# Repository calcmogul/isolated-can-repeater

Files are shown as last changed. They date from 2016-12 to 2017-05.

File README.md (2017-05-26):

# Galvanically Isolated CAN Repeater

This PCB is designed to function as a CAN repeater that galvanically isolates the two sides of the bus. It uses the repeater logic in figure 3 of AND8358/D (the application note for the AMIS-42700's feedback suppression).

## Hardware

* [Microcontroller](http://www.digikey.com/product-detail/en/texas-instruments/MSP430G2553IN20/296-28429-5-ND/2638885) (MSP430G2553) x1
* [Socket](http://www.digikey.com/product-detail/en/assmann-wsw-components/AR-20-HZL-TT/AE10015-ND/821769) (2x10 0.3" row spacing) x1
* [NOT Gates](http://www.digikey.com/product-detail/en/texas-instruments/CD4069UBE/296-3518-5-ND/376616) (CD4069UBE) x1
* [NAND Gates](http://www.digikey.com/product-detail/en/texas-instruments/CD4011BE/296-2031-5-ND/67241) (CD4011UBE) x1
* [CAN Transceiver](http://www.digikey.com/product-detail/en/texas-instruments/ISO1050DUBR/296-24818-2-ND/2094633) (ISO1050SUBR) x2
* [Voltage Regulator 3.3V](https://www.digikey.com/product-detail/en/stmicroelectronics/LD1117V33/497-1491-5-ND/586012) (LD1117V33) x1
* [0.1μF Capacitor](http://www.digikey.com/product-detail/en/vishay-bc-components/K104Z15Y5VF5TL2/BC1160CT-ND/286782) x1
* [10μF Capacitor](http://www.digikey.com/product-detail/en/tdk-corporation/FK24X5R1C106K/445-8497-ND/2815427) x1

### Thruhole

* 1x4 pin header x3

### SMT

* 2x6 pin header x1

## MSP430 Software

See [MSP430 README](msp430/README.md).

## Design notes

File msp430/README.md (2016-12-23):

# MSP430 Software

## Dependencies

* msp430-elf-gcc
* mspdebug

## Max operation speed of circuit

The falling edge of the output needs to track the input within one clock cycle of the CAN bus. Otherwise, one side of the bus will temporarily give up dominant status on the bus to the other side unintentionally.

measured delay between a falling edge on the input and the output tracking it:
> 1.88us (compiled with -O3 and using 16MHz main clock)

> 1/(1.88*1E-6)*1E-3 = ~531.9149kHz max switching frequency

So we could use a max bus speed of 500kHz with this hardware implementation.

The delay between the output tracking a rising edge on the input stops the local side of the bus from asserting dominance for a period of time so the other side of the bus may do so. This delay should be at least long enough for a falling edge (dominant state) to propagate across the bus.

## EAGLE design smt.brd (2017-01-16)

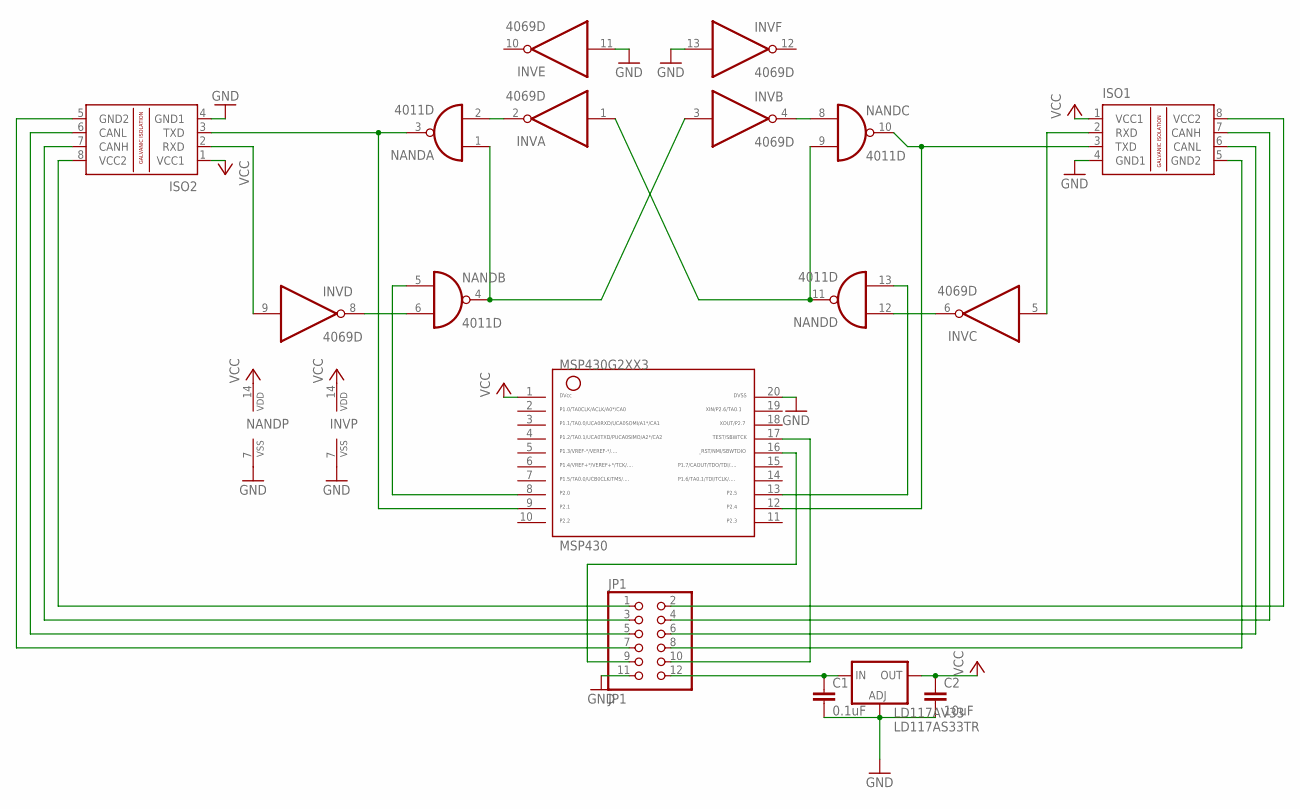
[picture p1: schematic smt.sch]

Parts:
C1: 0.1uF; C0402
C2: 10uF; C0402
INV: 4069D; SO14
ISO1, ISO2: ISO1050DUB; DUB-R-PDSO-G8
JP1: JP1; 2X06
LD117AV33: LD117AS33TR; SOT223
MSP430: G2XX3---PW20; PW20
NAND: 4011D; SO14

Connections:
GND: C1.2, C2.2, INV.7 (VSS), INV.11 (I), INV.13 (I), ISO1.4 (GND1), ISO2.4 (GND1), JP1.11, LD117AV33.1 (ADJ), MSP430.20, NAND.7 (VSS)
unnamed: JP1.9, MSP430.16
unnamed: JP1.10, MSP430.17
unnamed: INV.8 (O), NAND.6 (I1)
unnamed: INV.2 (O), NAND.2 (I1)
unnamed: INV.4 (O), NAND.8 (I0)
unnamed: INV.6 (O), NAND.12 (I0)
unnamed: INV.1 (I), NAND.9 (I1), NAND.11 (O)
unnamed: INV.3 (I), NAND.1 (I0), NAND.4 (O)
unnamed: ISO2.8 (VCC2), JP1.1
unnamed: ISO2.7 (CANH), JP1.3
unnamed: ISO2.6 (CANL), JP1.5
unnamed: ISO2.5 (GND2), JP1.7
unnamed: ISO1.8 (VCC2), JP1.2
unnamed: ISO1.7 (CANH), JP1.4
unnamed: ISO1.6 (CANL), JP1.6
unnamed: ISO1.5 (GND2), JP1.8
unnamed: INV.5 (I), ISO1.2 (RXD)
unnamed: INV.9 (I), ISO2.2 (RXD)
unnamed: MSP430.8, NAND.5 (I0)
unnamed: MSP430.13, NAND.13 (I1)
unnamed: C1.1, JP1.12, LD117AV33.3 (IN)
unnamed: ISO2.3 (TXD), MSP430.9, NAND.3 (O)
unnamed: ISO1.3 (TXD), MSP430.12, NAND.10 (O)
VCC: C2.1, INV.14 (VDD), ISO1.1 (VCC1), ISO2.1 (VCC1), LD117AV33.4 (OUT), MSP430.1, NAND.14 (VDD)

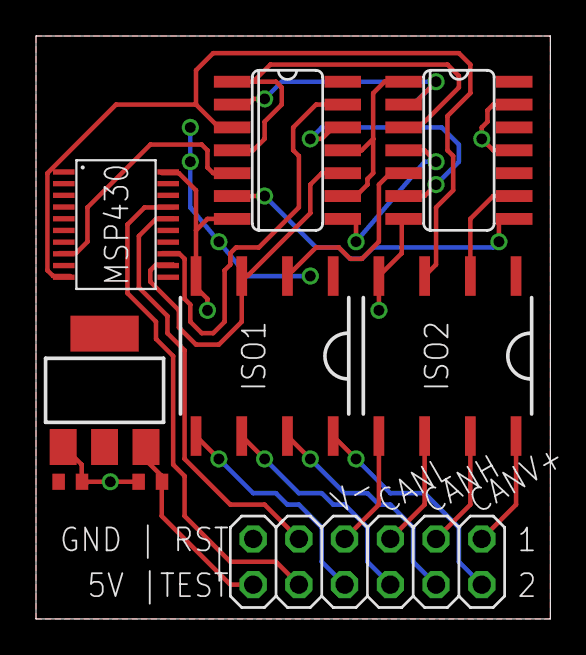
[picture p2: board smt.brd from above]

Board: 2 copper layers, 28.6 x 32.4 mm, 9 parts (0 on the bottom side), 25 nets.

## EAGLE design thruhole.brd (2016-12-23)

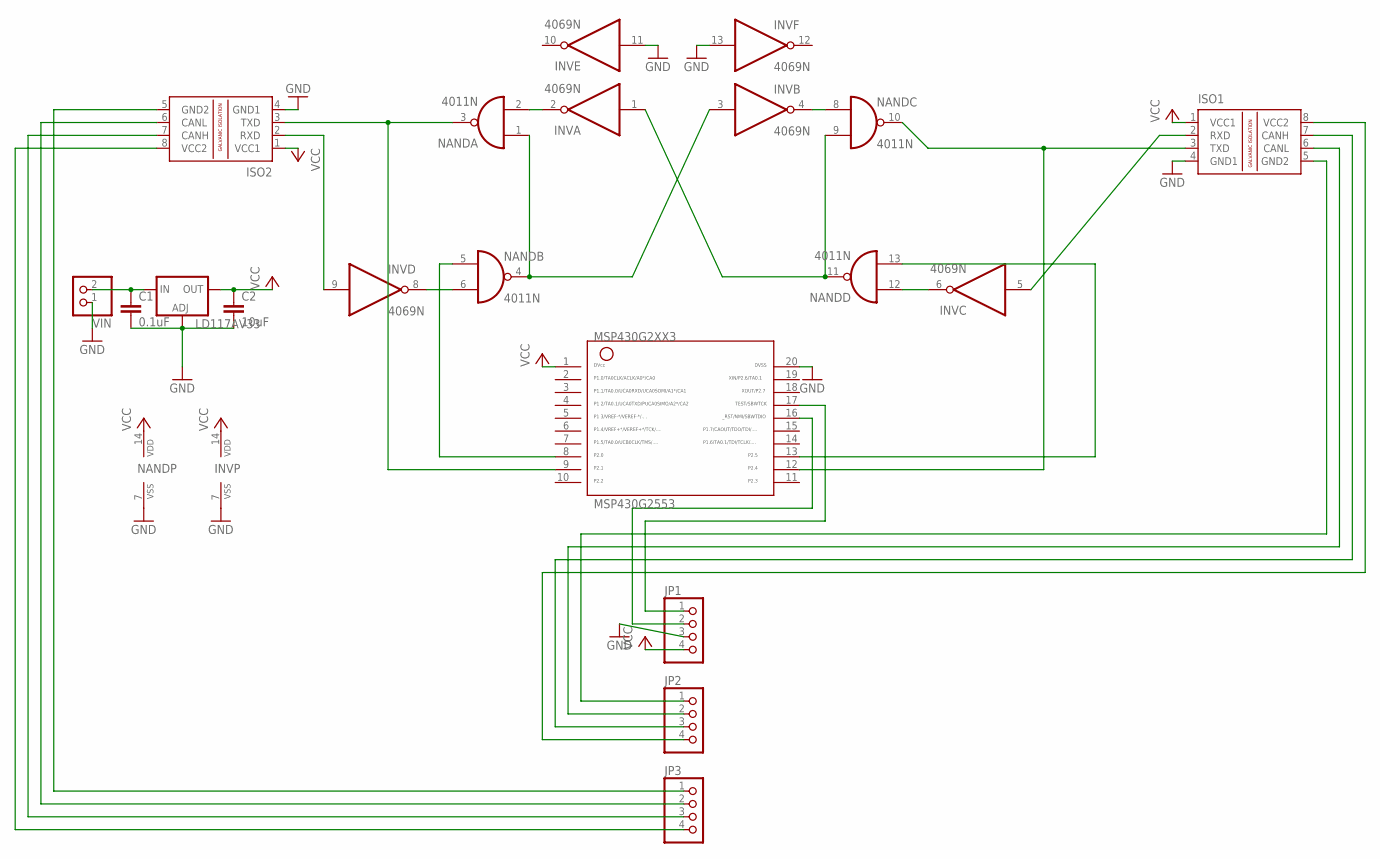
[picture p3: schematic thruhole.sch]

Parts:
C1: 0.1uF; C025-024X044
C2: 10uF; C025-024X044
INV: 4069N; DIL14
ISO1, ISO2: ISO1050DUB; DUB-R-PDSO-G8
JP1, JP2, JP3: PINHD-1X4; 1X04
LD117AV33: LD117AV33; TO220L1
MSP430G2553: G2XX3---N20; N20
NAND: 4011N; DIL14
VIN: PINHD-1X2; 1X02

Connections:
GND: C1.2, C2.2, INV.7 (VSS), INV.11 (I), INV.13 (I), ISO1.4 (GND1), ISO2.4 (GND1), JP1.3, LD117AV33.1 (ADJ), MSP430G2553.20, NAND.7 (VSS), VIN.1
unnamed: JP1.2, MSP430G2553.16
unnamed: JP1.1, MSP430G2553.17
unnamed: INV.8 (O), NAND.6 (I1)
unnamed: INV.2 (O), NAND.2 (I1)
unnamed: INV.4 (O), NAND.8 (I0)
unnamed: INV.6 (O), NAND.12 (I0)
unnamed: INV.1 (I), NAND.9 (I1), NAND.11 (O)
unnamed: INV.3 (I), NAND.1 (I0), NAND.4 (O)
unnamed: ISO2.8 (VCC2), JP3.4
unnamed: ISO2.7 (CANH), JP3.3
unnamed: ISO2.6 (CANL), JP3.2
unnamed: ISO2.5 (GND2), JP3.1
unnamed: ISO1.8 (VCC2), JP2.4
unnamed: ISO1.7 (CANH), JP2.3
unnamed: ISO1.6 (CANL), JP2.2
unnamed: ISO1.5 (GND2), JP2.1
unnamed: INV.5 (I), ISO1.2 (RXD)
unnamed: INV.9 (I), ISO2.2 (RXD)
unnamed: MSP430G2553.8, NAND.5 (I0)
unnamed: MSP430G2553.13, NAND.13 (I1)
unnamed: C1.1, LD117AV33.3 (IN), VIN.2
unnamed: ISO2.3 (TXD), MSP430G2553.9, NAND.3 (O)
unnamed: ISO1.3 (TXD), MSP430G2553.12, NAND.10 (O)
VCC: C2.1, INV.14 (VDD), ISO1.1 (VCC1), ISO2.1 (VCC1), JP1.4, LD117AV33.2 (OUT), MSP430G2553.1, NAND.14 (VDD)

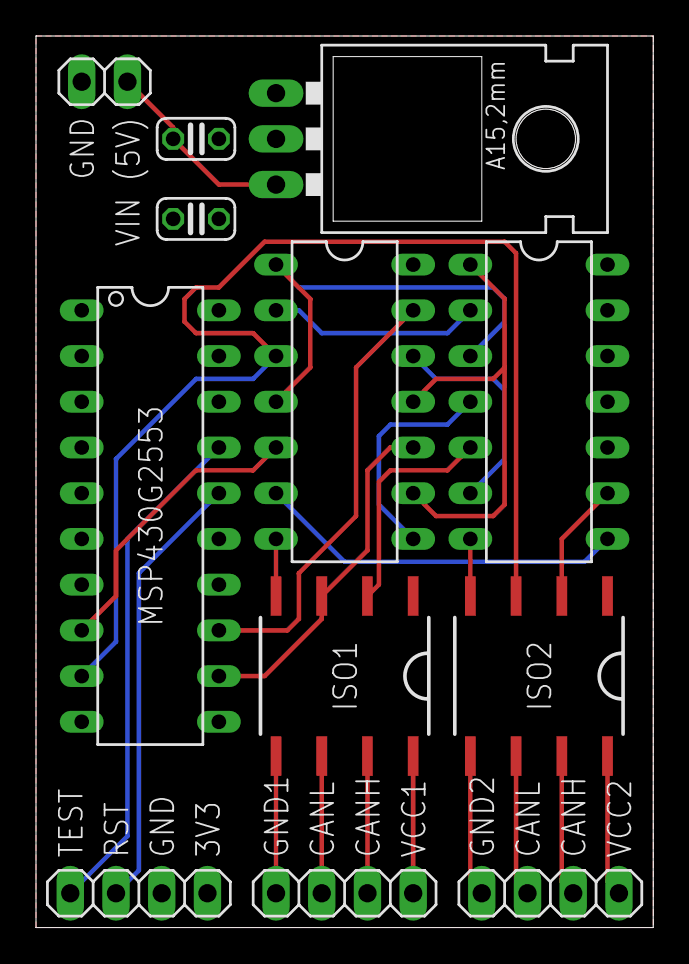
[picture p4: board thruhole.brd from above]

Board: 2 copper layers, 34.3 x 49.5 mm, 12 parts (0 on the bottom side), 25 nets.

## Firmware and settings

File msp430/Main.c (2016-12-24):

// Copyright (c) Tyler Veness 2016. All Rights Reserved.

#include <msp430g2553.h>
#include <stdint.h>

const uint16_t kDelayCount = 1600;

// 0 = low; 1 = high
uint8_t prevInputPins = 0;
uint8_t currentInputPins = 0;

void checkPins(const uint8_t input, const uint8_t output,
               volatile unsigned int* ACCR0, volatile unsigned int* CCTL1);

/*
 * Software loop is used instead of GPIO interrupts on edges because a rising
 * and falling edge can both occur while processing another interrupt. To avoid
 * that ambiguity, the edges are determined in the software loop at the rate
 * they can be processed.
 */
int main() {
  // Stop watchdog
  WDTCTL = WDTPW | WDTHOLD;

  // Set clock to 1 MHz
  DCOCTL = 0;
  BCSCTL1 = CALBC1_16MHZ;
  DCOCTL = CALDCO_16MHZ;

  // Configure P2.0, P2.1, P2.4, and P2.5 for GPIO
  P2SEL &= ~(BIT0 | BIT1 | BIT4 | BIT5);

  P2DIR |= BIT0;   // P2.0 = output for ISO2
  P2DIR &= ~BIT1;  // P2.1 = input for ISO2
  P2DIR &= ~BIT4;  // P2.4 = input for ISO1
  P2DIR |= BIT5;   // P2.5 = output for ISO1

  // Set ISO1 output high
  P2OUT |= BIT5;

  // Set ISO2 output high
  P2OUT |= BIT0;

  /* The delay from ISO1 CAN to ISO2 CAN is ~150ns (under typical conditions) -
   * it's the time needed to receive the signal on one bus plus the time needed
   * to transmit the signal on the other bus - the total delay is equal to the
   * loop delay of one transceiver.
   *
   * A delay of 300ns needs at least a 3.333MHz clock to capture one count.
   * kDelayCount = period * freq
   *             = std::ceil(300ns * 16MHz) to achieve minimum delay of 300ns
   */

  // Stop timer
  TA0CCR0 = 0;
  TA1CCR0 = 0;

  // CCIE = Interrupt when timer counts to TACCR0
  TA0CCTL0 = CCIE;
  TA1CCTL0 = CCIE;

  // Source Timer A from SMCLK (TASSEL_2), up mode (MC_1).
  // Up mode counts up to TACCR0. SLAU144J p. 358
  TA0CTL = TASSEL_2 | MC_1;
  TA1CTL = TASSEL_2 | MC_1;

  __bis_SR_register(GIE);

  while (1) {
    currentInputPins = P2IN;
    checkPins(BIT4, BIT5, &TA0CCR0, &TA0CCTL1);
    checkPins(BIT1, BIT0, &TA1CCR0, &TA1CCTL1);
    prevInputPins = currentInputPins;
  }
}

void checkPins(const uint8_t input, const uint8_t output,
               volatile unsigned int* ACCR0, volatile unsigned int* CCTL1) {
  // If input toggled low
  if ((prevInputPins & input) != 0 && (currentInputPins & input) == 0) {
    // Set output to low immediately
    P2OUT &= ~output;

    /* Stop timer if it's running. This is guaranteed to not be reordered
     * after clearing the interrupt flag by the compiler due to the registers
     * being marked as volatile.
     */
    *ACCR0 = 0;

    // Clear potential pending timer interrupt
    *CCTL1 &= ~CCIFG;
  } else if ((prevInputPins & input) == 0 && (currentInputPins & input) != 0) {
    // Else was toggled high. Start delay timer.

    // Start timer by initializing counter register value
    *ACCR0 = kDelayCount;
  }
}

// This will be called when timer counts to TA0CCR0
void __interrupt_vec(TIMER0_A0_VECTOR) TA0CCR0_ISR() {
  // Set ISO1 output high
  P2OUT |= BIT5;

  // Stop timer
  TA0CCR0 = 0;

  /* Clear interrupt flag so any interrupts generated in the ISR before stopping
   * the timer aren't serviced
   */
  TA0CCTL0 &= ~CCIFG;
}

// This will be called when timer counts to TA1CCR0
void __interrupt_vec(TIMER1_A0_VECTOR) TA1CCR0_ISR() {
  // Set ISO2 output high
  P2OUT |= BIT0;

  // Stop timer
  TA1CCR0 = 0;

  /* Clear interrupt flag so any interrupts generated in the ISR before stopping
   * the timer aren't serviced
   */
  TA1CCTL0 &= ~CCIFG;
}

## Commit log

2016-12-14 Pin pitch of TI's MSP430 N20 package now aligns with grid
    [main.brd, main.sch]
2016-12-14 Reduced board height a bit
    [main.brd]
2016-12-15 Replaced MSP430 with correct IC (MSP430G2553), improved board annotations, and added parts list to README
    [main.brd, main.sch]
2016-12-17 Moved some traces to the top layer
    [main.brd]
2016-12-17 PCB tweaks in pursuit of a planar design (not working)
    [main.brd, main.sch]
2016-12-17 Chose different socket
2016-12-17 Moved some traces to the bottom layer to fix plane isolation and shorten the trace lengths
    [main.brd]
2016-12-17 Shrunk the board height a bit
    [main.brd]
2016-12-17 Rotated gates 90 CCW to achieve smaller board with much shorter traces
    [main.brd, main.sch]
2016-12-18 Added pin annotations
    [main.brd, main.sch]
2016-12-18 Chose different 10uF capacitor and updated links to capacitors
2016-12-18 Ran wpiformat
    [main.brd, main.sch]
2016-12-18 Replaced incorrect component and converted README to Markdown
    Replaced NOR gates with NAND gates to match AMIS schematic and updated parts list to reflect the change.
    [main.brd, main.sch]
2016-12-18 Added pin headers to parts list and replaced listed socket
2016-12-20 Created SMT version of PCB
    [smt.brd, smt.sch, thruhole.brd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]
2016-12-22 Moved components on thruhole board closer together and swapped pin headers for 1x12 pin header
    [smt.brd, thruhole.brd, thruhole.sch]
2016-12-22 Adjusted SMT board pin labels
    [smt.brd]
2016-12-23 msp430: software was tested with a logic analyzer and debugged
    The GPIO interrupts were replaced with a software loop to avoid simultaneous GPIO rising and falling edges.
    [Main.c]
2016-12-23 Separated thruhole 1x12 pin header into 3 1x4 pin headers for rules compliance
    [thruhole.brd, thruhole.sch]
2016-12-24 Reorganized schematics
    [smt.sch, thruhole.sch]
2017-01-16 Removed errant trace from SMT board
    [smt.brd]
2017-05-26 Replaced SparkFun voltage regulator link with one from Digi-Key
